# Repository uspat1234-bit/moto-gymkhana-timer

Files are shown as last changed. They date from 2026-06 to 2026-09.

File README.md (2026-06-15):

# MGTS (Moto Gymkhana Timing System) 🏍️⏱️


[]()
[]()

モトジムカーナの競技向けに設計された、高可用性・超低遅延のハイブリッド計時システム（Hardware & Software）です。

## 概要 (Overview)
屋外の過酷な通信環境やノイズ（雨滴、落ち葉、遮断状態の継続など）に耐えうるインフラグレードの設計思想を取り入れています。センサーからのトリガー信号を、ルーター不要の超低遅延無線プロトコル（ESP-NOW）と、物理LAN（W5500モジュールによるUDPブロードキャスト）の2経路で同時に送信する **Active-Active型の超冗長ネットワークアーキテクチャ** を採用しています。

## 主な特徴 (Features)
* **究極のネットワーク冗長化:** L2層（ESP-NOW）とL3層（有線LAN）の同時パケット送出により、パケットロスを物理的に回避。
* **高精度なエッジトリガー制御:** 20msのソフトウェアデバウンスと送信ロック機構により、センサー前での滞留による通信ストームを完全に防止。
* **拡張性の高いPCアプリ連携:** 計時処理とマトリクスLED表示を行うメインコア基板から、JSON形式のUDPパケットでPC（Flutter/Fletアプリ）へ結果をリアルタイム送信。
* **Hardware as Code:** 回路図や基板レイアウトはテキスト（JSONベース）でGit管理され、完全なトレーサビリティを確保。

## ハードウェア・インターフェース仕様 (Hardware Interfaces)

### メインLED基板 (Main Display Core)
筐体にマウントされた物理アーケードボタン（GPIO 22）を用いて、運用時のリカバリー操作やモード切替を行います。
* **短押し (50ms ～ 2秒未満): 強制DNF（リタイア）処理**
  * 転倒やコースアウト時など、現在計測中のランナーの記録を即座に「999.999 (DNF)」として確定・送信し、次の出走者の計測待機状態へ強制移行します。
* **長押し (2秒以上): シングルセンサーモード切替**
  * 画面に「SINGLE ON / OFF」と表示され、モードがトグルで切り替わります。
  * **SINGLE ON:** 8の字練習などで、1つのセンサーを「スタート」と「ゴール」の両方に兼用（ラップ計測）するモードです。

### センサーノード基板 (Sensor Node)
* **センサー入力 (GPIO 21):**
  * OMRON製光電センサー（E3Z-R66など）からのNPN信号を監視します。
  * 遮断された瞬間のエッジを検知し、チャタリングフィルター（20ms）を通過後、システム全体へトリガーパケットを送出します。

## システムアーキテクチャ (Architecture)

1. **Sensor Node (スタート / ゴール)**
   * XIAO ESP32-C6 + W5500モジュールで構成。
   * トリガー検知と同時に `START` または `STOP` コマンドを無線/有線でマルチキャスト。
2. **Main Display Core (LEDパネル基板)**
   * センサーからのコマンドを非同期で待ち受ける計時サーバー。
   * 64x8 マトリクスLEDによるリアルタイムな状態表示とタイム描画。
3. **Frontend App (PC側)**
   * Python/Fletで構築されたフロントエンドUI。
   * UDP経由での確定リザルト受信、および任意のエントリー番号予約や強制DNFコマンドの送信。

## ディレクトリ構成 (Directory Structure)

モノレポ（Monorepo）構成を採用し、ハードウェア構成とソフトウェアのバージョン整合性を担保しています。

```text
.
├── README.md                 # 本ドキュメント
├── hardware/                 # ハードウェア設計ファイル・BOM
│   ├── BOM.md                # 統合部品表（メイン表示部・センサーノード部）
│   ├── main_board/           # メインLED基板の回路図およびPCBレイアウト (EasyEDA)
│   └── sensor_node/          # センサー基板の回路図およびPCBレイアウト (EasyEDA)
├── esp32-c6_sketch/          # XIAO ESP32-C6用 ファームウェアソース (Arduino C++)
│   ├── main_board/
│   └── sensor_node/
└── app/                      # PC側表示・管理用アプリケーション (Python/Flet) ※今後実装予定

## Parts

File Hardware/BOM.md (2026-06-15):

# MGTS (Moto Gymkhana Timing System) 総合部品表 (BOM)

本ドキュメントは、計時システム（MGTS）を構成する「メイン表示部（LEDパネル）」および「センサーノード部（スタート・ゴール）」の調達部品一式を管理する構成管理データです。

---

## 1. メイン表示部 (LEDパネル側) × 1台分

| 大項目 | 品目 | 数量 | 金額 | 購入先リンク / 備考 |
| :--- | :--- | :---: | :---: | :--- |
| 内部基板 | 基板 | 1 | 160円 | [JLCPCB][1] |
| 内部基板 | ESP32-C6 | 1 | 1,650円 | [Amazon：マイコン本体][2] (3個パックを流用) |
| 内部基板 | ヒートシンク | 4 | 460円 | [Amazon：ヒートシンク][3] |
| 内部基板 | ダウンコンバータ | 2 | 260円 | [Amazon：ダウンコンバータ][4] |
| 内部基板 | W5500 | 1 | 833円 | [Amazon：W5500モジュール][5] |
| 内部基板 | 抵抗(10K) | 1 | 10円 | [Amazon：抵抗アソートパック][6] |
| 内部基板 | 抵抗(330) | 1 | 10円 | [Amazon：抵抗アソートパック][6] |
| 内部基板 | XHソケット(2pin) | 4 | 200円 | [Amazon：XHコネクタキット][7] |
| 内部基板 | XHソケット(3pin） | 1 | 50円 | [Amazon：XHコネクタキット][7] |
| 内部基板 | コンデンサ(1000uf) | 3 | 213円 | [Amazon：コンデンサ1000uf][8] |
| インターフェイス | LANポート | 1 | 350円 | [Amazon：パネルマウントLAN][11] |
| インターフェイス | wifiアンテナ | 1 | 450円 | [Amazon：アンテナ本体][12] |
| インターフェイス | wifiアンテナケーブル | 1 | 172円 | [Amazon：アンテナ用ケーブル][13] |
| インターフェイス | DCジャック | 1 | 44円 | [Amazon：パネルマウントDCジャック][14] |
| インターフェイス | 12vPDケーブル | 1 | 600円 | [Amazon：Type-C PDトリガーケーブル][15] |
| インターフェイス | 内部配線と接続ジャック | - | - | [Amazon：内部配線][16] / [Amazon：ジャック][17] |
| インターフェイス | USBポート | 1 | 700円 | [Amazon：パネルマウントUSB][25] |
| インターフェイス | アーケードボタン | 1 | 362円 | [Amazon：三和 OBSF-30][26] (物理リセット/モード切替) |
| ケース関連 | ケース | 1 | - | 既存資産流用または別途調達 |
| ケース関連 | スタンド台座 | 2 | 1,060円 | [Amazon：スタンド台座][20] |
| ケース関連 | ファン(共通) | 1 | 225円 | [Amazon：5Vファン][21] |
| ケース関連 | ファン(シロッコ) | 1 | 1,200円 | [Amazon：シロッコファン][27] (排熱用強力ブロワー) |
| ケース関連 | ファンフィルター | 1 | 146円 | [Amazon：ファンフィルター][22] |
| ケース関連 | HX分岐ファン用 | 1 | 100円 | [Amazon：ファン用分岐ケーブル][28] |
| ケース関連 | LEDパネル | 2 | 6,400円 | [Amazon：64x8 LEDマトリクス][29] |
| ケース関連 | LEDパネル保護板 | 1 | 1,500円 | [はざいや：アクリル板(グレースモーク)][30] (直射日光対策) |
| ケース関連 | ケース固定ステー | 2 | 1,140円 | [Amazon：固定ステー][31] |
| ケース関連 | パネル用両面テープ | 1 | 1,500円 | [Amazon：超強力両面テープ][32] |
| その他 | モバイルバッテリー | 1 | 8,000円 | [Amazon：アンカー大容量バッテリー][23] (87w/20000mAh) |
| その他 | LANケーブル | 1 | - | 既存資産流用 |
| その他 | スタンド | 2 | - | 既存資産流用 |
| その他 | ケース保護角 | 2 | 176円 | [Amazon：コーナーガード][33] |

---

## 2. センサーノード部 (スタート / ゴール共通) × 2台分合計

| 大項目 | 品目 | 数量 | 金額 | 購入先リンク / 備考 |
| :--- | :--- | :---: | :---: | :--- |
| 内部基板 | 基板 | 2 | 320円 | [JLCPCB][1] |
| 内部基板 | ESP32-C6 | 2 | 3,300円 | [Amazon：マイコン本体][2] (3個パック) |
| 内部基板 | ヒートシンク | 6 | 690円 | [Amazon：ヒートシンク][3] |
| 内部基板 | ダウンコンバータ | 2 | 260円 | [Amazon：ダウンコンバータ][4] |
| 内部基板 | W5500 | 2 | 1,666円 | [Amazon：W5500モジュール][5] |
| 内部基板 | 抵抗(10K) | 2 | 20円 | [Amazon：抵抗アソートパック][6] |
| 内部基板 | 抵抗(1K) | 2 | 20円 | [Amazon：抵抗アソートパック][6] |
| 内部基板 | XHソケット(2pin) | 4 | 200円 | [Amazon：XHコネクタキット][7] |
| 内部基板 | XHソケット(3pin） | 2 | 100円 | [Amazon：XHコネクタキット][7] |
| 内部基板 | コンデンサ(1000uf) | 4 | 284円 | [Amazon：コンデンサ1000uf][8] |
| 内部基板 | コンデンサ(0.1uf) | 2 | 200円 | [Amazon：コンデンサ0.1uf][9] |
| 内部基板 | フォトカプラ | 2 | 180円 | [Amazon：フォトカプラ][10] (センサー信号の絶縁用) |
| インターフェイス | LANポート | 2 | 700円 | [Amazon：パネルマウントLAN][11] |
| インターフェイス | wifiアンテナ | 2 | 900円 | [Amazon：アンテナ本体][12] |
| インターフェイス | wifiアンテナケーブル | 2 | 344円 | [Amazon：アンテナ用ケーブル][13] |
| インターフェイス | DCジャック | 2 | 88円 | [Amazon：パネルマウントDCジャック][14] |
| インターフェイス | 12vPDケーブル | 2 | 1,200円 | [Amazon：Type-C PDトリガーケーブル][15] |
| インターフェイス | 内部配線と接続ジャック | - | - | [Amazon：内部配線][16] / [Amazon：ジャック][17] |
| インターフェイス | センサー | 2 | - | OMRON [E3Z-R66 公式製品ページ][18] |
| ケース関連 | ケース | 2 | 2,600円 | [Amazon：防水/防塵ケース][19] |
| ケース関連 | スタンド台座 | 2 | 1,060円 | [Amazon：スタンド台座][20] |
| ケース関連 | ファン | 2 | 450円 | [Amazon：5Vファン][21] |
| ケース関連 | ファンフィルター | 2 | 292円 | [Amazon：ファンフィルター][22] |
| その他 | モバイルバッテリー | 2 | 16,000円 | [Amazon：アンカー大容量バッテリー][23] (87w/20000mAh) |
| その他 | LANケーブル | 2 | - | 既存資産流用 |
| その他 | スタンド(本体と反射板) | 4 | - | 既存資産流用 |
| その他 | 反射板 | 2 | - | [モノタロウ：アクリル反射板][24] |

---

### 🔗 共通リファレンスURL定義（一元管理）

[1]: https://jlcpcb.com/jp/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
[2]: https://www.amazon.co.jp/XIAO-ESP32C6-3%E5%80%8B%E3%83%91%E3%83%83%E3%82%AF-2-4GHz-5-0%E3%80%81Zigbee%E3%80%81Mater%E3%80%81Thread%E3%80%81%E3%82%AA%E3%83%B3%E3%83%9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
[3]: https://www.amazon.co.jp/dp/B0F8V4H91N
[4]: https://www.amazon.co.jp/dp/B0CGVMRQXB
[5]: https://www.amazon.co.jp/dp/B0FZ42HVNH
[6]: https://www.amazon.co.jp/%E7%82%AD%E7%B4%A0%E7%9A%AE%E8%86%9C%E6%8A%B5%E6%8A%97%E5%99%A8-30%E7%A8%AE%E5%90%8410%E6%9C%AC-10%CE%A9%E3%80%9C1M%CE%A9-%E9%9B%BB%E5%AD%90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
[7]: https://www.amazon.co.jp/XH%E3%82%AD%E3%83%83%E3%83%88-XH%E5%9E%8B%E7%AB%AF%E5%AD%90-%E3%82%B3%E3%83%B3%E3%82%BF%E3%82%AF%E3%83%88%E3%83%94%E3%83%B3-2-54mm%E3%83%94%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
[8]: https://www.amazon.co.jp/dp/B0FP5FLN5M
[9]: https://www.amazon.co.jp/%E6%9D%91%E7%94%B0%E8%A3%BD%E4%BD%9C%E6%89%80-MURATA-%E7%A9%8D%E5%B1%A4%E3%82%BB%E3%83%A9%E3%83%A3%E3%83%9F%E3%83%83%E3%82%AF%E3%82%B3%E3%83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
[10]: https://www.amazon.co.jp/dp/B09ZQRX29R
[11]: https://www.amazon.co.jp/gp/product/B0989ZYJH8
[12]: https://www.amazon.co.jp/dp/B09JBMLWTT
[13]: https://www.amazon.co.jp/dp/B0931SL6LG
[14]: https://www.amazon.co.jp/dp/B0FQBRHRLY
[15]: https://www.amazon.co.jp/dp/B0D3QG33J7
[16]: https://www.amazon.co.jp/dp/B0DJPQ6KT3
[17]: https://www.amazon.co.jp/dp/B011IJUKC4
[18]: https://www.fa.omron.co.jp/product/item/E3Z-R66/
[19]: https://www.amazon.co.jp/dp/B0F1ZT5SKT
[20]: https://www.amazon.co.jp/dp/B0F21DBYRP
[21]: https://www.amazon.co.jp/dp/B0G7GJZ6JC
[22]: https://www.amazon.co.jp/dp/B0G2R57LNK
[23]: https://www.amazon.co.jp/dp/B0CXNVT5J4
[24]: https://www.monotaro.com/g/04975913/
[25]: https://www.amazon.co.jp/dp/B0G12TWVNH
[26]: https://www.amazon.co.jp/%E4%B8%89%E5%92%8C%E9%9B%BB%E5%AD%90-Sanwa-OBSF-30-K-%E3%83%8F%E3%83%A1%E8%BE%BC%E3%81%BF%E5%BC%8F%E6%8A%BC%E3%81%97%E3%83%9C%E3%82%BF%E3%83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
[27]: https://www.amazon.co.jp/dp/B09G5RC5FF
[28]: https://www.amazon.co.jp/dp/B0GKTWP3LL
[29]: https://www.amazon.co.jp/dp/B088M21SPB
[30]: https://www.hazaiya.co.jp/
[31]: https://www.amazon.co.jp/dp/B003UCG5Y0
[32]: https://www.amazon.co.jp/dp/B01BXNSL8K
[33]: https://www.amazon.co.jp/dp/B0F27MNCGT

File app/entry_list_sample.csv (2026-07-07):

タグID | ゼッケン | 選手名 | クラス
A001 | 1 | 山田 太郎 | A
A002 | 2 | 佐藤 次郎 | A
A003 | 3 | 鈴木 健太 | A
A004 | 4 | 高橋 大輔 | A
B001 | 11 | 田中 宏 | B
B002 | 12 | 伊藤 達也 | B
B003 | 13 | 渡辺 剛 | B
B004 | 14 | 山本 修 | B
C001 | 21 | 中村 翔 | C
C002 | 22 | 小林 誠 | C
C003 | 23 | 加藤 涼 | C
C004 | 24 | 吉田 優 | C
D001 | 31 | 山田 花子 | D
D002 | 32 | 佐藤 結衣 | D
D003 | 33 | 鈴木 美咲 | D
D004 | 34 | 高橋 凛 | D

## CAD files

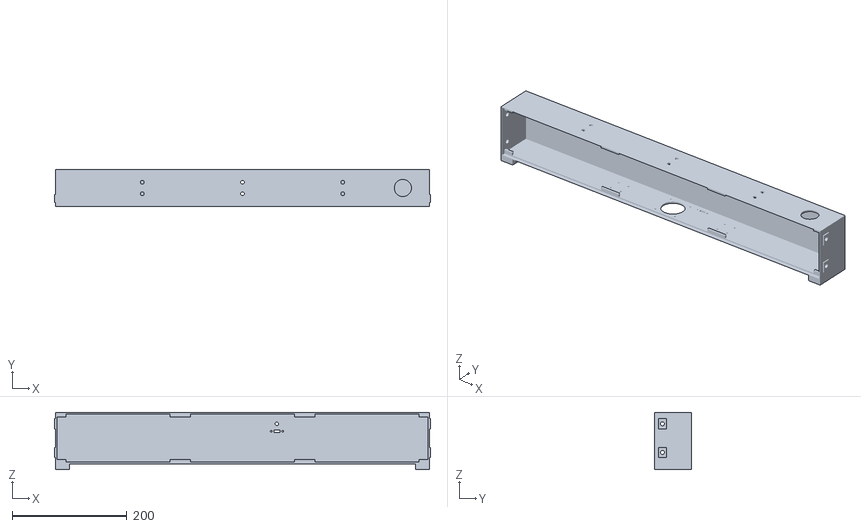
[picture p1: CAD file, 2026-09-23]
Hardware/case/full.stl
656.5 x 65.0 x 100.0

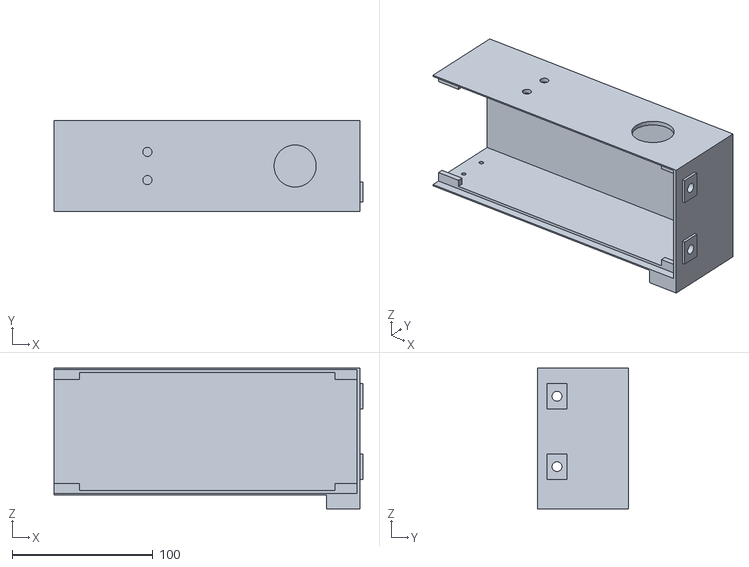
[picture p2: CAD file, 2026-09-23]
Hardware/case/right.stl
219.7 x 65.0 x 100.0

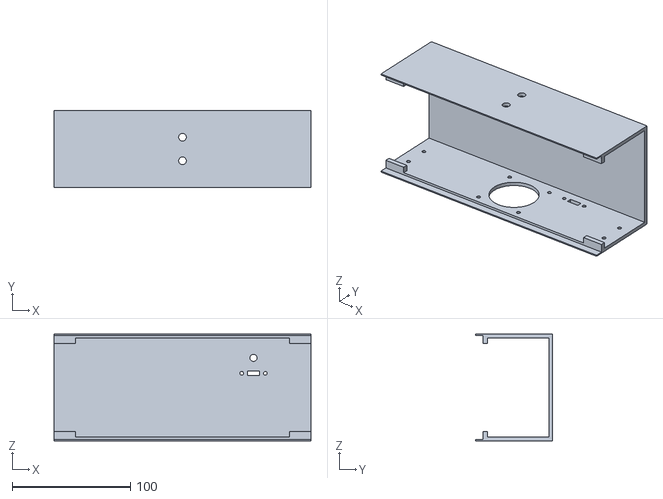
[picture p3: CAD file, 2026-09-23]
Hardware/case/center.stl
217.2 x 65.0 x 90.0

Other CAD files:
Hardware/case/left.stl

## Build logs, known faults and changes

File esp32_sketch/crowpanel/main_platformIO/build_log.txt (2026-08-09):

Processing advance-hmi (platform: https://github.com/Jason2866/platform-espressif32.git; board: ESP32-S3-WROOM-1-N16R8; framework: arduino)
--------------------------------------------------------------------------------
Verbose mode can be enabled via `-v, --verbose` option
CONFIGURATION: https://docs.platformio.org/page/boards/espressif32/ESP32-S3-WROOM-1-N16R8.html
PLATFORM: Espressif 32 (2026.6.50+sha.2979fbd) > ESP32-S3-16MB-Flash-8MB-PSRAM
HARDWARE: ESP32S3 240MHz, 8MB RAM, 16MB Flash
DEBUG: Current (esp-builtin) On-board (esp-builtin) External (cmsis-dap, esp-bridge, esp-prog, esp-prog-2, iot-bus-jtag, jlink, minimodule, olimex-arm-usb-ocd, olimex-arm-usb-ocd-h, olimex-arm-usb-tiny-h, olimex-jtag-tiny, tumpa)
PACKAGES: 
 - contrib-piohome @ 3.4.4 
 - framework-arduinoespressif32 @ 3.3.10+sha.67336dba 
 - tool-esptoolpy @ 5.3.0 
 - tool-xtensa-esp-elf-gdb @ 17.1.0+20260402 
 - toolchain-xtensa-esp-elf @ 15.2.0+20251204
LDF: Library Dependency Finder -> https://bit.ly/configure-pio-ldf
LDF Modes: Finder ~ chain, Compatibility ~ soft
Library Manager: Installing WiFiClientSecure
Warning! Could not find the package with 'WiFiClientSecure' requirements
Found 39 compatible libraries
Scanning dependencies...
Dependency Graph
|-- lvgl @ 8.3.11
|-- LovyanGFX @ 1.2.19
|-- Adafruit SSD1306 @ 2.5.13
|-- TAMC_GT911 @ 1.0.2
|-- TCA9554 @ 0.1.1
|-- Adafruit BusIO @ 1.17.0
|-- ArduinoJson @ 6.21.6
|-- RTClib @ 2.1.4
|-- FS @ 3.3.10
|-- LittleFS @ 3.3.10
|-- SD @ 3.3.10
|-- SPI @ 3.3.10
|-- Wire @ 3.3.10
Building in release mode
Linking .pio\build\advance-hmi\firmware.elf
C:\Users\admin\.platformio\penv\Scripts\platformio.exe : C:/Users/admin/.platformio/packages/toolchain-xtensa
-esp-elf/bin/../lib/gcc/xtensa-esp-elf/15.2.0/../../../../xtensa-esp-elf/bin/ld.exe: .pio/build/advance-hmi/s
rc/ui_events.cpp.o (symbol from plugin): in function `pt_count':
発生場所 行:1 文字:1
+ C:\Users\admin\.platformio\penv\Scripts\platformio.exe run > build_lo ...
+ ~~~~~~~~~~~~~~~~~~~~~~~~~~~~~~~~~~~~~~~~~~~~~~~~~~~~~~~~~~~~~~~~~~~~~
    + CategoryInfo          : NotSpecified: (C:/Users/admin/...ion `pt_count'::String) [], RemoteException
    + FullyQualifiedErrorId : NativeCommandError
 
(.text+0x0): multiple definition of `pt_count'; .pio/build/advance-hmi/src/main.cpp.o (symbol from plugin):(.
text+0x0): first defined here
C:/Users/admin/.platformio/packages/toolchain-xtensa-esp-elf/bin/../lib/gcc/xtensa-esp-elf/15.2.0/../../../..
/xtensa-esp-elf/bin/ld.exe: .pio/build/advance-hmi/src/ui_events.cpp.o (symbol from plugin): in function `pt_
count':
(.text+0x0): multiple definition of `is_mc'; .pio/build/advance-hmi/src/main.cpp.o (symbol from plugin):(.tex
t+0x0): first defined here
.pio/libdeps/advance-hmi/LovyanGFX/src/lgfx/v1/LGFXBase.hpp:1390:9: warning: type 'struct LovyanGFX' violates
 the C++ One Definition Rule [-Wodr]
 1390 |   class LovyanGFX : public
      |         ^
.pio/libdeps/advance-hmi/LovyanGFX/src/lgfx/v1/LGFXBase.hpp:1390:9: note: a type with the same name but diffe
rent base type is defined in another translation unit
 1390 |   class LovyanGFX : public
      |         ^
.pio/libdeps/advance-hmi/LovyanGFX/src/lgfx/v1/lgfx_filesystem_support.hpp:45:9: note: type name 'lgfx::v1::L
GFX_FILESYSTEM_Support<lgfx::v1::LGFXBase>' should match type name 'lgfx::v1::LGFXBase'
   45 |   class LGFX_FILESYSTEM_Support : public Base
      |         ^
.pio/libdeps/advance-hmi/LovyanGFX/src/lgfx/v1/LGFXBase.hpp:56:9: note: the incompatible type is defined here
   56 |   class LGFXBase
      |         ^
.pio/libdeps/advance-hmi/LovyanGFX/src/lgfx/v1/LGFXBase.hpp:1405:9: warning: type 'struct LGFX_Device' violat
es the C++ One Definition Rule [-Wodr]
 1405 |   class LGFX_Device : public LovyanGFX
      |         ^
.pio/libdeps/advance-hmi/LovyanGFX/src/lgfx/v1/LGFXBase.hpp:1405:9: note: a type with different bases is defi
ned in another translation unit
 1405 |   class LGFX_Device : public LovyanGFX
      |         ^
.pio/libdeps/advance-hmi/LovyanGFX/src/lgfx/v1/LGFXBase.hpp:1508:18: warning: type of 'init_impl' does not ma
tch original declaration [-Wlto-type-mismatch]
 1508 |     virtual bool init_impl(bool use_reset, bool use_clear);
      |                  ^
.pio/libdeps/advance-hmi/LovyanGFX/src/lgfx/v1/LGFXBase.cpp:3521:8: note: 'init_impl' was previously declared
 here
 3521 |   bool LGFX_Device::init_impl(bool use_reset, bool use_clear)
      |        ^
.pio/libdeps/advance-hmi/LovyanGFX/src/lgfx/v1/LGFXBase.cpp:3521:8: note: code may be misoptimized unless '-f
no-strict-aliasing' is used
.pio/libdeps/advance-hmi/LovyanGFX/src/lgfx/v1/LGFXBase.hpp:1408:5: warning: type of '__ct_base ' does not ma
tch original declaration [-Wlto-type-mismatch]
 1408 |     LGFX_Device(void);
      |     ^
.pio/libdeps/advance-hmi/LovyanGFX/src/lgfx/v1/LGFXBase.cpp:3498:3: note: '__ct_base ' was previously declare
d here
 3498 |   LGFX_Device::LGFX_Device(void)
      |   ^
.pio/libdeps/advance-hmi/LovyanGFX/src/lgfx/v1/LGFXBase.cpp:3498:3: note: code may be misoptimized unless '-f
no-strict-aliasing' is used
.pio/libdeps/advance-hmi/LovyanGFX/src/lgfx/v1/LGFXBase.hpp:1416:10: warning: type of 'setPanel' does not mat
ch original declaration [-Wlto-type-mismatch]
 1416 |     void setPanel(Panel_Device* panel);
      |          ^
.pio/libdeps/advance-hmi/LovyanGFX/src/lgfx/v1/LGFXBase.cpp:3513:8: note: 'setPanel' was previously declared 
here
 3513 |   void LGFX_Device::setPanel(Panel_Device* panel)
      |        ^
.pio/libdeps/advance-hmi/LovyanGFX/src/lgfx/v1/LGFXBase.cpp:3513:8: note: code may be misoptimized unless '-f
no-strict-aliasing' is used
lto-wrapper.exe: warning: using serial compilation of 8 LTRANS jobs
lto-wrapper.exe: note: see the '-flto' option documentation for more information
.pio/libdeps/advance-hmi/LovyanGFX/src/lgfx/v1/LGFXBase.hpp:1390:9: warning: type 'struct LovyanGFX' violates
 the C++ One Definition Rule [-Wodr]
 1390 |   class LovyanGFX : public
      |         ^
.pio/libdeps/advance-hmi/LovyanGFX/src/lgfx/v1/LGFXBase.hpp:1390:9: note: a type with the same name but diffe
rent base type is defined in another translation unit
.pio/libdeps/advance-hmi/LovyanGFX/src/lgfx/v1/lgfx_filesystem_support.hpp:45:9: note: type name 'lgfx::v1::L
GFX_FILESYSTEM_Support<lgfx::v1::LGFXBase>' should match type name 'lgfx::v1::LGFXBase'
   45 |   class LGFX_FILESYSTEM_Support : public Base
      |         ^
.pio/libdeps/advance-hmi/LovyanGFX/src/lgfx/v1/LGFXBase.hpp:56:9: note: the incompatible type is defined here
   56 |   class LGFXBase
      |         ^
.pio/libdeps/advance-hmi/LovyanGFX/src/lgfx/v1/LGFXBase.hpp:1390:9: warning: type 'struct LovyanGFX' violates
 the C++ One Definition Rule [-Wodr]
 1390 |   class LovyanGFX : public
      |         ^
.pio/libdeps/advance-hmi/LovyanGFX/src/lgfx/v1/LGFXBase.hpp:1390:9: note: a type with the same name but diffe
rent base type is defined in another translation unit
.pio/libdeps/advance-hmi/LovyanGFX/src/lgfx/v1/lgfx_filesystem_support.hpp:45:9: note: type name 'lgfx::v1::L
GFX_FILESYSTEM_Support<lgfx::v1::LGFXBase>' should match type name 'lgfx::v1::LGFXBase'
   45 |   class LGFX_FILESYSTEM_Support : public Base
      |         ^
.pio/libdeps/advance-hmi/LovyanGFX/src/lgfx/v1/LGFXBase.hpp:56:9: note: the incompatible type is defined here
   56 |   class LGFXBase
      |         ^
.pio/libdeps/advance-hmi/LovyanGFX/src/lgfx/v1/LGFXBase.hpp:1390:9: warning: type 'struct LovyanGFX' violates
 the C++ One Definition Rule [-Wodr]
 1390 |   class LovyanGFX : public
      |         ^
.pio/libdeps/advance-hmi/LovyanGFX/src/lgfx/v1/LGFXBase.hpp:1390:9: note: a type with the same name but diffe
rent base type is defined in another translation unit
.pio/libdeps/advance-hmi/LovyanGFX/src/lgfx/v1/lgfx_filesystem_support.hpp:45:9: note: type name 'lgfx::v1::L
GFX_FILESYSTEM_Support<lgfx::v1::LGFXBase>' should match type name 'lgfx::v1::LGFXBase'
   45 |   class LGFX_FILESYSTEM_Support : public Base
      |         ^
.pio/libdeps/advance-hmi/LovyanGFX/src/lgfx/v1/LGFXBase.hpp:56:9: note: the incompatible type is defined here
   56 |   class LGFXBase
      |         ^
collect2.exe: error: ld returned 1 exit status
*** [.pio\build\advance-hmi\firmware.elf] Error 1
========================= [FAILED] Took 18.55 seconds =========================

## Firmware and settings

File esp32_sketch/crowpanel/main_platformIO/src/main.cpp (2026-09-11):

#include "pins_config.h"
#include "LovyanGFX_Driver.h"

#include <Arduino.h>
#include <lvgl.h>
#include <Wire.h>
#include <SPI.h>
#include <SD.h>
#include <stdbool.h>
#include <ArduinoJson.h>
#include <RTClib.h>
#include <vector>
#include <map>

#include "ui.h"

// ==========================================
// ハードウェアピン設定
// ==========================================
#define SD_MOSI 6
#define SD_MISO 4
#define SD_SCK  5
#define SD_CS   7

// ==========================================
// ハードウェア・ディスプレイ用オブジェクト
// ==========================================
LGFX gfx;
RTC_PCF8563 rtc;
unsigned long lastTimeUpdate = 0;

// RTCから起動時に1回だけ取得した基準時刻 (GT911初期化後はRTCへの再アクセスを避けるため)
DateTime bootDateTime;
unsigned long bootMillis = 0;

DateTime getRtcNowCached() {
    unsigned long elapsedSec = (millis() - bootMillis) / 1000;
    return bootDateTime + TimeSpan(elapsedSec);
}

SPIClass SD_SPI = SPIClass(HSPI);

HardwareSerial C6Serial(1);

static lv_disp_draw_buf_t draw_buf;
static lv_color_t *buf;
static lv_color_t *buf1;

uint16_t touch_x, touch_y;

LV_FONT_DECLARE(font_jp_14);

unsigned long lastC6DataMillis = 0;
bool c6Connected = false;
unsigned long lastC6StatusCheck = 0;

// MC自動判定用の下限タイム(秒)。0以下の場合は自動判定を行わない
float mcThresholdSeconds = 0.0f;

lv_obj_t * current_editing_row = NULL;

extern int pt_count;
extern bool is_mc;

void on_master_row_clicked(lv_event_t * e) {
    current_editing_row = lv_event_get_target(e);
    lv_obj_clear_flag(ui_Panel4, LV_OBJ_FLAG_HIDDEN);

    lv_obj_t * no_label = ui_comp_get_child(current_editing_row, UI_COMP_MASTERROW_MASTERROW1NO);
    lv_obj_t * class_label = ui_comp_get_child(current_editing_row, UI_COMP_MASTERROW_MASTERROW1CLASS);
    lv_textarea_set_placeholder_text(ui_TextArea2, lv_label_get_text(no_label));
    lv_textarea_set_placeholder_text(ui_TextArea3, lv_label_get_text(class_label));

    lv_textarea_set_text(ui_TextArea2, "");
    lv_textarea_set_text(ui_TextArea3, "");

    pt_count = 0;
    is_mc = false;
    lv_label_set_text(ui_Label33, "+ 0 Sec");
    lv_keyboard_set_textarea(ui_Keyboard2, ui_TextArea2);
}

struct RiderInfo {
    String tagId;
    String bib;
    String lastName;
    String firstName;
    String riderClass;
};
std::vector<RiderInfo> riderDatabase;

struct ResultRecord {
    String tagId;
    String bib;
    String name;
    String riderClass;
    float  baseTime;
    int    penaltySeconds;
    bool   isMC;
    float  finalTime;
    String reactText;
    unsigned long recvMillis;
    lv_obj_t * rowObj;
};
std::vector<ResultRecord> masterLogs;

std::map<String, String> pendingNotes;
std::map<String, int> bestIndexByBib;
std::map<String, int> bibBestIndex;   // bib単位でのベスト記録（pb_日付.csv保存専用。ランキング集約とは独立）

std::vector<String> classList;
String masterTargetClass = "X";
String resultFilterClass = "ALL";

int unknownCounter = 0;

void rebuildResultTab();
void registerClass(String className);
void updateClassDropdown();
void savePersonalBestToSD();

void set_backlight(uint8_t brightness) {
    if (brightness > 245) brightness = 245;
    Wire.beginTransmission(0x30);
    Wire.write(brightness);
    Wire.endTransmission();
}
void buzzer_start() { Wire.beginTransmission(0x30); Wire.write(246); Wire.endTransmission(); }
void buzzer_stop()  { Wire.beginTransmission(0x30); Wire.write(247); Wire.endTransmission(); }
void speaker_on()   { Wire.beginTransmission(0x30); Wire.write(248); Wire.endTransmission(); }
void speaker_off()  { Wire.beginTransmission(0x30); Wire.write(249); Wire.endTransmission(); }

void my_disp_flush(lv_disp_drv_t *disp, const lv_area_t *area, lv_color_t *color_p) {
    if (gfx.getStartCount() > 0) gfx.endWrite();
    gfx.pushImageDMA(area->x1, area->y1, area->x2 - area->x1 + 1, area->y2 - area->y1 + 1, (lgfx::rgb565_t *)&color_p->full);
    lv_disp_flush_ready(disp);
}
void my_touchpad_read(lv_indev_drv_t * indev_driver, lv_indev_data_t * data) {
    data->state = LV_INDEV_STATE_REL;
    bool touched = gfx.getTouch(&touch_x, &touch_y);
    if (touched) {
        data->state = LV_INDEV_STATE_PR;
        data->point.x = touch_x;
        data->point.y = touch_y;
    }
}

String formatTime(float t) {
    if (t < 0) return "-";
    int minutes = (int)t / 60;
    float seconds = t - (minutes * 60.0f);
    char buf[16];
    snprintf(buf, sizeof(buf), "%d:%06.3f", minutes, seconds);
    return String(buf);
}

String buildPenMemoText(const ResultRecord &r) {
    if (r.isMC) return "MC";
    if (r.penaltySeconds > 0) return "+" + String(r.penaltySeconds) + "s";
    return "";
}

String buildFullName(const String &lastName, const String &firstName) {
    String trimmedFirst = firstName;
    trimmedFirst.trim();
    if (trimmedFirst.length() == 0) {
        return lastName;
    }
    return lastName + "　" + trimmedFirst;
}

void loadEntryList() {
    riderDatabase.clear();
    File file = SD.open("/entry_list.csv", FILE_READ);
    if (!file) {
        Serial.println("entry_list.csv が見つかりません");
        return;
    }

    bool isHeader = true;
    while (file.available()) {
        String line = file.readStringUntil('\n');
        line.trim();
        if (line.length() == 0) continue;
        if (isHeader) { isHeader = false; continue; }

        int idx1 = line.indexOf(',');
        int idx2 = line.indexOf(',', idx1 + 1);
        int idx3 = line.indexOf(',', idx2 + 1);
        int idx4 = line.indexOf(',', idx3 + 1);
        if (idx1 < 0 || idx2 < 0 || idx3 < 0 || idx4 < 0) continue;

        RiderInfo info;
        info.tagId      = line.substring(0, idx1);
        info.bib        = line.substring(idx1 + 1, idx2);
        info.lastName   = line.substring(idx2 + 1, idx3);
        info.firstName  = line.substring(idx3 + 1, idx4);
        info.riderClass = line.substring(idx4 + 1);
        info.tagId.trim(); info.bib.trim(); info.lastName.trim(); info.firstName.trim(); info.riderClass.trim();

        riderDatabase.push_back(info);
        registerClass(info.riderClass);
    }
    file.close();
    Serial.printf("選手名簿読込完了: %d 名\n", riderDatabase.size());
    updateClassDropdown();
}

RiderInfo* findRiderByTagId(const String &tagId) {
    for (auto &r : riderDatabase) if (r.tagId == tagId) return &r;
    return nullptr;
}
RiderInfo* findRiderByBib(const String &bib) {
    for (auto &r : riderDatabase) if (r.bib == bib) return &r;
    return nullptr;
}

void registerClass(String className) {
    className.trim();
    if (className.length() == 0) return;
    for (auto &c : classList) {
        if (c == className) return;
    }
    classList.push_back(className);
    updateClassDropdown();
}

void updateClassDropdown() {
    String options = "ALL";
    for (auto &c : classList) {
        options += "\n" + c;
    }
    lv_dropdown_set_options(ui_Dropdown1, options.c_str());
}

float getPreviousBestTime(const String &tagId, const String &bib, int excludeIndex) {
    float best = -1.0f;
    for (int i = 0; i < (int)masterLogs.size(); i++) {
        if (i == excludeIndex) continue;
        ResultRecord &r = masterLogs[i];
        if (r.isMC) continue;
        bool sameRider = false;
        if (tagId != "X999") {
            sameRider = (r.tagId == tagId);
        } else {
            sameRider = (r.tagId == "X999"); // X999同士は常に同一人物とみなす
        }
        if (sameRider) {
            if (best < 0 || r.finalTime < best) best = r.finalTime;
        }
    }
    return best;
}

float getOverallTopTime() {
    float top = -1.0f;
    for (auto &r : masterLogs) {
        if (r.isMC) continue;
        if (top < 0 || r.finalTime < top) top = r.finalTime;
    }
    return top;
}

float getClassTopTime(const String &riderClass) {
    float top = -1.0f;
    for (auto &r : masterLogs) {
        if (r.isMC) continue;
        if (r.riderClass != riderClass) continue;
        if (top < 0 || r.finalTime < top) top = r.finalTime;
    }
    return top;
}

void addMasterRowUI(int index) {
    ResultRecord &r = masterLogs[index];

    lv_obj_t * row = ui_MasterRow_create(ui_ListContainer);
    lv_obj_set_user_data(row, (void*)(intptr_t)index);
    lv_obj_add_event_cb(row, on_master_row_clicked, LV_EVENT_CLICKED, NULL);
    lv_obj_move_to_index(row, 0);

    lv_obj_t * rank_label  = ui_comp_get_child(row, UI_COMP_MASTERROW_MASTERROW1RANK);
    lv_obj_t * class_label = ui_comp_get_child(row, UI_COMP_MASTERROW_MASTERROW1CLASS);
    lv_obj_t * no_label    = ui_comp_get_child(row, UI_COMP_MASTERROW_MASTERROW1NO);
    lv_obj_t * name_label  = ui_comp_get_child(row, UI_COMP_MASTERROW_MASTERROW1NAME);
    lv_obj_t * time_label  = ui_comp_get_child(row, UI_COMP_MASTERROW_MASTERROW1TIME);
    lv_obj_t * react_label = ui_comp_get_child(row, UI_COMP_MASTERROW_MASTERROW1REACT);
    lv_obj_t * memo_label  = ui_comp_get_child(row, UI_COMP_MASTERROW_MASTERROW1PENMEMO);

    lv_obj_set_style_text_font(name_label, &font_jp_14, 0);
    lv_label_set_long_mode(name_label, LV_LABEL_LONG_CLIP);
    lv_obj_set_height(name_label, LV_SIZE_CONTENT);

    lv_label_set_text_fmt(rank_label, "%d", (int)masterLogs.size());
    lv_label_set_text(class_label, r.riderClass.c_str());
    lv_label_set_text(no_label, r.bib.c_str());
    lv_label_set_text(name_label, r.name.c_str());
    lv_label_set_text(time_label, r.isMC ? "MC" : formatTime(r.finalTime).c_str());
    lv_label_set_text(react_label, r.reactText.c_str());
    lv_label_set_text(memo_label, buildPenMemoText(r).c_str());

    r.rowObj = row;
}

void refreshMasterRowUI(int index) {
    ResultRecord &r = masterLogs[index];
    if (r.rowObj == nullptr) return;

    lv_obj_t * class_label = ui_comp_get_child(r.rowObj, UI_COMP_MASTERROW_MASTERROW1CLASS);
    lv_obj_t * no_label    = ui_comp_get_child(r.rowObj, UI_COMP_MASTERROW_MASTERROW1NO);
    lv_obj_t * name_label  = ui_comp_get_child(r.rowObj, UI_COMP_MASTERROW_MASTERROW1NAME);
    lv_obj_t * time_label  = ui_comp_get_child(r.rowObj, UI_COMP_MASTERROW_MASTERROW1TIME);
    lv_obj_t * memo_label  = ui_comp_get_child(r.rowObj, UI_COMP_MASTERROW_MASTERROW1PENMEMO);

    lv_obj_set_style_text_font(name_label, &font_jp_14, 0);
    lv_label_set_text(class_label, r.riderClass.c_str());
    lv_label_set_text(no_label, r.bib.c_str());
    lv_label_set_text(name_label, r.name.c_str());
    lv_label_set_text(time_label, r.isMC ? "MC" : formatTime(r.finalTime).c_str());
    lv_label_set_text(memo_label, buildPenMemoText(r).c_str());
}

void rebuildResultTab() {
    bestIndexByBib.clear();

    for (int i = 0; i < (int)masterLogs.size(); i++) {
        ResultRecord &r = masterLogs[i];
        if (r.isMC) continue;

        // bib単位で集計する（以前はtagId=="X999"の場合だけ全員まとめていたが、
        // 電源再投入後に復元された記録はtagIdが空文字になるため挙動が不整合になっていた。
        // bibは常にユニーク(X1, X2, X3...)なので、bib基準に統一する）
        String bestKey = r.bib;

        auto it = bestIndexByBib.find(bestKey);
        if (it == bestIndexByBib.end()) {
            bestIndexByBib[bestKey] = i;
        } else {
            if (r.finalTime < masterLogs[it->second].finalTime) {
                it->second = i;
            }
        }
    }

    float overallBestTime = -1.0f;
    for (auto &kv : bestIndexByBib) {
        ResultRecord &r = masterLogs[kv.second];
        if (overallBestTime < 0 || r.finalTime < overallBestTime) {
            overallBestTime = r.finalTime;
        }
    }

    std::vector<int> candidates;
    for (auto &kv : bestIndexByBib) {
        ResultRecord &r = masterLogs[kv.second];
        if (resultFilterClass == "ALL" || r.riderClass == resultFilterClass) {
            candidates.push_back(kv.second);
        }
    }

    std::sort(candidates.begin(), candidates.end(), [](int a, int b) {
        ResultRecord &ra = masterLogs[a];
        ResultRecord &rb = masterLogs[b];
        if (ra.finalTime != rb.finalTime) return ra.finalTime < rb.finalTime;
        return ra.bib.toInt() < rb.bib.toInt();
    });

    if (candidates.size() > 5) candidates.resize(5);

    float topTime = overallBestTime;

    lv_obj_clean(ui_ListContainer2);

    for (int rank = 0; rank < (int)candidates.size(); rank++) {
        ResultRecord &r = masterLogs[candidates[rank]];

        lv_obj_t * row = ui_ResultRow_create(ui_ListContainer2);

        lv_obj_t * rank_label  = ui_comp_get_child(row, UI_COMP_RESULTROW_RESULTROW1RANK);
        lv_obj_t * class_label = ui_comp_get_child(row, UI_COMP_RESULTROW_RESULTROW1CLASS);
        lv_obj_t * no_label    = ui_comp_get_child(row, UI_COMP_RESULTROW_RESULTROW1NO);
        lv_obj_t * name_label  = ui_comp_get_child(row, UI_COMP_RESULTROW_RESULTROW1NAME);
        lv_obj_t * time_label  = ui_comp_get_child(row, UI_COMP_RESULTROW_RESULTROW1TIME);
        lv_obj_t * top_label   = ui_comp_get_child(row, UI_COMP_RESULTROW_RESULTROW1TOP);
        lv_obj_t * react_label = ui_comp_get_child(row, UI_COMP_RESULTROW_RESULTROW1REACT);
        lv_obj_t * memo_label  = ui_comp_get_child(row, UI_COMP_RESULTROW_RESULTROW1PENMEMO);

        lv_obj_set_style_text_font(name_label, &font_jp_14, 0);
        lv_label_set_text_fmt(rank_label, "%d", rank + 1);
        lv_label_set_text(class_label, r.riderClass.c_str());
        lv_label_set_text(no_label, r.bib.c_str());
        lv_label_set_text(name_label, r.name.c_str());
        lv_label_set_text(time_label, formatTime(r.finalTime).c_str());
        lv_label_set_text(react_label, r.reactText.c_str());
        lv_label_set_text(memo_label, buildPenMemoText(r).c_str());

        if (topTime <= 0) {
            lv_label_set_text(top_label, "100.000%");
        } else {
            float ratio = (r.finalTime / topTime) * 100.0f;
            int ratioX1000 = (int)(ratio * 1000.0f);   // 3桁精度で切り捨て
            char buf[16];
            snprintf(buf, sizeof(buf), "%d.%03d%%", ratioX1000 / 1000, ratioX1000 % 1000);
            lv_label_set_text(top_label, buf);
        }
    }
}

// ==========================================
// 個人ベストの永続化 (RTC安全読み取り版)
// ==========================================
String getPersonalBestFilename() {
    DateTime now = getRtcNowCached();
    char filename[32];
    sprintf(filename, "/pb_%04d%02d%02d.csv", now.year(), now.month(), now.day());
    return String(filename);
}

void savePersonalBestToSD() {
    String filename = getPersonalBestFilename();
    File f = SD.open(filename, FILE_WRITE);
    if (!f) {
        Serial.println(filename + " 書き込み失敗");
        return;
    }
    f.println("bib,name,class,time");
    for (auto &kv : bibBestIndex) {   // ★ bib単位の管理に変更（身元不明選手が1枠に集約されないように）
        ResultRecord &best = masterLogs[kv.second];
        f.printf("%s,%s,%s,%.3f\n",
            best.bib.c_str(), best.name.c_str(), best.riderClass.c_str(), best.finalTime);
    }
    f.close();
}

void loadPersonalBestFromSD() {
    String filename = getPersonalBestFilename();
    File f = SD.open(filename, FILE_READ);
    if (!f) {
        Serial.println(filename + " が見つかりません(本日はじめてのセッション)");
        return;
    }

    bool isHeader = true;
    while (f.available()) {
        String line = f.readStringUntil('\n');
        line.trim();
        if (line.length() == 0) continue;
        if (isHeader) { isHeader = false; continue; }

        int idx1 = line.indexOf(',');
        int idx2 = line.indexOf(',', idx1 + 1);
        int idx3 = line.indexOf(',', idx2 + 1);
        if (idx1 < 0 || idx2 < 0 || idx3 < 0) continue;

        ResultRecord rec;
        rec.bib = line.substring(0, idx1);
        rec.name = line.substring(idx1 + 1, idx2);
        rec.riderClass = line.substring(idx2 + 1, idx3);
        rec.finalTime = line.substring(idx3 + 1).toFloat();
        rec.baseTime = rec.finalTime;
        rec.penaltySeconds = 0;
        rec.isMC = false;
        rec.tagId = "";
        rec.rowObj = nullptr;

        masterLogs.push_back(rec);
        int idx = masterLogs.size() - 1;
        bestIndexByBib[rec.bib] = idx;
        bibBestIndex[rec.bib] = idx;   // ★ bib単位の管理にも復元する

        // bibが"X"+数字(例:"X12")の形式なら、unknownCounterを復元して番号の衝突を防ぐ
        if (rec.bib.startsWith("X")) {
            int num = rec.bib.substring(1).toInt();
            if (num > unknownCounter) unknownCounter = num;
        }

        registerClass(rec.riderClass);
    }
    f.close();
    Serial.printf("個人ベスト復元完了(%s): %d 名\n", filename.c_str(), bestIndexByBib.size());
}

// ==========================================
// MC threshold (下限タイムによる自動MC判定)
// ==========================================
void setMcThreshold(int minutes, int seconds, int ms100, int ms10, int ms1) {
    int milliseconds = ms100 * 100 + ms10 * 10 + ms1;
    mcThresholdSeconds = minutes * 60.0f + seconds + milliseconds / 1000.0f;
    Serial.printf("[MC閾値] 設定: %d分%02d秒.%03d (%.3f秒)\n",
        minutes, seconds, milliseconds, mcThresholdSeconds);
}

void processResult(String tagId, float rawTime) {
    RiderInfo* rider = findRiderByTagId(tagId);
    String bib, name, riderClass;

    if (tagId == "X999") {
        unknownCounter++;
        bib = "X" + String(unknownCounter);   // 例: "X1", "X15" など、短く表記
        name = "";
        riderClass = masterTargetClass;
    } else if (rider == nullptr) {
        bib = tagId;
        name = "";
        riderClass = masterTargetClass;
    } else {
        bib = rider->bib;
        name = buildFullName(rider->lastName, rider->firstName);
        riderClass = rider->riderClass;
    }

    registerClass(riderClass);

    ResultRecord rec;
    rec.tagId = tagId;
    rec.bib = bib;
    rec.name = name;
    rec.riderClass = riderClass;
    rec.baseTime = rawTime;
    rec.penaltySeconds = 0;

    // 下限タイムを下回っていたら、自動的にMC判定
    if (mcThresholdSeconds > 0 && rawTime < mcThresholdSeconds) {
        rec.isMC = true;
        Serial.printf("[自動MC] タイム %.3f秒 < 閾値 %.3f秒 のため、MC判定\n", rawTime, mcThresholdSeconds);
    } else {
        rec.isMC = false;
    }

    rec.finalTime = rec.isMC ? INFINITY : rawTime;
    rec.recvMillis = millis();
    rec.rowObj = nullptr;

    auto noteIt = pendingNotes.find(tagId);
    if (noteIt != pendingNotes.end()) {
        rec.reactText = noteIt->second;
        pendingNotes.erase(noteIt);
    }

    masterLogs.push_back(rec);
    int newIndex = masterLogs.size() - 1;

    // bib単位でのベスト記録を更新（保存用。ランキング集約(bestIndexByBib)とは独立して管理する）
    {
        auto bIt = bibBestIndex.find(bib);
        if (bIt == bibBestIndex.end() || masterLogs[newIndex].finalTime < masterLogs[bIt->second].finalTime) {
            bibBestIndex[bib] = newIndex;
        }
    }

    addMasterRowUI(newIndex);

    long total_ms = (long)round(rawTime * 1000.0);
    Serial0.printf("T:%ld\n", total_ms);

    // MC判定された場合、ファステスト系の読み上げは行わない(除外ロジックにより自動的に対象外)
    if (!rec.isMC) {
        float prevBest = getPreviousBestTime(tagId, bib, newIndex);
        bool isPersonalBest = (prevBest < 0 || rawTime < prevBest);

        float overallTop = getOverallTopTime();
        bool isOverallFastest = (fabs(rawTime - overallTop) < 0.0005f);

        if (isOverallFastest) {
            Serial0.println("W:overall_fastest");
        } else {
            float classTop = getClassTopTime(riderClass);
            bool isClassFastest = (fabs(rawTime - classTop) < 0.0005f);

            if (isClassFastest) {
                Serial0.println("W:class_fastest");
            }
            if (isPersonalBest) {
                Serial0.println("W:personal_best");
            }

            if (overallTop > 0) {
                float ratio = (rawTime / overallTop) * 100.0f;
                int ratioX10 = (int)(ratio * 10.0f); // 直接1桁精度で切り捨て
                Serial0.printf("P:%d\n", ratioX10);
            }
        }
    }

    rebuildResultTab();
    savePersonalBestToSD();
}

void processJsonMessage(String jsonStr) {
    StaticJsonDocument<256> doc;
    if (deserializeJson(doc, jsonStr)) return;

    String type = doc["type"].as<String>();
    String id = doc["id"] | "X999";

    if (type == "RESULT") {
        float t = doc["time"].as<float>();
        processResult(id, t);

    } else if (type == "REACTION") {
        float diff = doc["diff"] | 0.0f;
        pendingNotes[id] = "React:" + String(diff, 3) + "s";

    } else if (type == "FLYING") {
        float diff = doc["diff"] | 0.0f;
        pendingNotes[id] = "FLYING(" + String(diff, 3) + "s)";

    } else if (type == "SEQ_START") {
        Serial.println("[SEQ] シグナル開始");

    } else if (type == "FORCE_DNF") {
        Serial.println("[SEQ] コースリセット");
    }
}

void importCsvData() {
    Serial.println("UIから importCsvData が呼ばれました！");
    loadEntryList();
}

void sendManualTrigger(String type) {
    C6Serial.println(type);
    Serial.println("[MANUAL] " + type + " を送信しました");
}

void queueResultVoice(float total_seconds) {
    long ms = (long)round(total_seconds * 1000.0);
    Serial0.printf("T:%ld\n", ms);
}
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
void loop() {
    lv_timer_handler();
    delay(5);

    if (millis() - lastTimeUpdate > 1000) {
        updateTimeDisplay();
        lastTimeUpdate = millis();
    }

    if (millis() - lastC6StatusCheck > 10000) {
        updateC6ConnectionStatus();
        lastC6StatusCheck = millis();
    }

    if (C6Serial.available() > 0) {
        String input = C6Serial.readStringUntil('\n');
        input.trim();

        lastC6DataMillis = millis();

        Serial.println(input);

        if (input.startsWith("[ESP_DATA]")) {
            input.replace("[ESP_DATA]", "");
            input.trim();
            processJsonMessage(input);
        }
    }

    if (Serial.available() > 0) {
        String input = Serial.readStringUntil('\n');
        input.trim();
        if (input.startsWith("[ESP_DATA]")) {
            input.replace("[ESP_DATA]", "");
            input.trim();
            processJsonMessage(input);
        } else if (input.startsWith("{")) {
            processJsonMessage(input);
        }
    }
}

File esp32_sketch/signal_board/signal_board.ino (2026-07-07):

/*
 * ====================================================================
 * MGTS (Moto Gymkhana Timing System) - Signal Board Core Unit
 * * [Architecture Highlights]
 * 1. 自律型カウントダウンシーケンス (Autonomous Countdown Sequence)
 * 2. キャストガード・フライング判定 (Cast-Guard Flying Detection)
 * 3. 共通エッジ・ステート管理: メイン基板同様、基本を X999 とし
 * ENTRY受信でIDを更新。ペナルティ検知時はIDを付与して送信。
 * 4. 多重起動ロック (Sequence Execution Lock):
 * 既にシグナルが進行している状態(isSequenceActive)で
 * 重複してSEQ_STARTを受信した場合、連打とみなして安全に破棄する。
 * ====================================================================
 */

#include <SPI.h>
#include <Ethernet.h>
#include <WiFi.h>
#include <esp_now.h>
#include <esp_wifi.h>
#include <Adafruit_GFX.h>
#include <Adafruit_NeoMatrix.h>
#include <driver/i2s.h>
#include <math.h>
#include <ArduinoJson.h>

/* ====================================================================
 * L3 ネットワーク構成 (有線LAN / W5500)
 * ==================================================================== */
IPAddress ip_eth(192, 168, 1, 30);      
IPAddress dns(192, 168, 1, 1);
IPAddress gateway(192, 168, 1, 1);
IPAddress subnet(255, 255, 255, 0);
byte mac[] = { 0xDE, 0xAD, 0xBE, 0xEF, 0xFE, 0x30 }; 
const int UDP_PORT   = 5005;            

/* ====================================================================
 * ハードウェア・ピン定義
 * ==================================================================== */
#define LED_PIN       21  
#define BTN_RESET     22  

#define ETH_CS_PIN    1   
#define ETH_RST_PIN   2   
#define SPI_SCK       19  
#define SPI_MISO      20  
#define SPI_MOSI      18  

#define PIN_BCK       23  
#define PIN_LCK       16  
#define PIN_DIN       17  
#define I2S_NUM       I2S_NUM_0

Adafruit_NeoMatrix matrix = Adafruit_NeoMatrix(64, 8, LED_PIN,
  NEO_MATRIX_TOP + NEO_MATRIX_LEFT + NEO_MATRIX_COLUMNS + NEO_MATRIX_ZIGZAG,
  NEO_GRB + NEO_KHZ800);

EthernetUDP ethUdp;
char packetBuffer[512]; 

/* ====================================================================
 * シグナル制御構造・ステート管理
 * ==================================================================== */
uint8_t hubAddress[] = {0x58, 0xE6, 0xC5, 0x12, 0x97, 0xCC};

unsigned long seqStartTime = 0;
unsigned long expectedGreenTime = 0;
unsigned long flyingStartTime = 0;

bool isSequenceActive = false;
bool hasStartedPhysical = false;

enum SignalState { STATE_READY, STATE_DELAY, STATE_RED1, STATE_RED2, STATE_YELLOW, STATE_GREEN, STATE_FLYING };
SignalState currentSignalState = STATE_READY;

String nextRiderID = "X999";
String currentRiderId = "X999";

int16_t sine_table[256];

/* ====================================================================
 * ユーティリティ・コア関数
 * ==================================================================== */
void showStatus(String txt, uint16_t color) {
  matrix.setTextColor(color);
  int x = (64 - (txt.length() * 6)) / 2; 
  matrix.setCursor(x >= 0 ? x : 0, 1); matrix.print(txt);
}

void notifyControlHub(String eventType, String id, float diffSec) {
  String json = "{\"type\":\"" + eventType + "\",\"id\":\"" + id + "\",\"diff\":" + String(diffSec, 3) + "}";
  esp_now_send(hubAddress, (uint8_t *)json.c_str(), json.length());
  Serial.println("[NOTIFY] " + json);
}

void playTone(float frequency, unsigned long duration_ms) {
  size_t bw; unsigned long num_samples = (44100 * duration_ms) / 1000; int16_t buffer[1024]; uint32_t phase = 0; uint32_t phase_step = (frequency * 4294967296.0) / 44100.0; 
  unsigned long samples_sent = 0;
  while (samples_sent < num_samples) {
    int to_send = min((unsigned long)512, num_samples - samples_sent);
    for (int i = 0; i < to_send; i++) {
      int env = 256; if (samples_sent + i < 1000) env = ((samples_sent + i) * 256) / 1000; else if (num_samples - (samples_sent + i) < 1000) env = ((num_samples - (samples_sent + i)) * 256) / 1000;
      buffer[i*2] = (sine_table[phase >> 24] * env) >> 8; buffer[i*2+1] = buffer[i*2]; phase += phase_step; 
    }
    i2s_write(I2S_NUM, buffer, to_send * 4, &bw, portMAX_DELAY); samples_sent += to_send;
  }
  i2s_zero_dma_buffer(I2S_NUM);
}

void playPenaltySound() {
  for(int i = 0; i < 6; i++) {
    playTone(2000, 60); 
    playTone(1400, 60); 
  }
  playTone(800, 400);
}

/* ====================================================================
 * 上位プロトコル・コマンドハンドラ
 * ==================================================================== */
void processCommand(String rawMsg) {
  String msg = rawMsg; msg.trim(); 
  
  if (msg.startsWith("{")) {
    JsonDocument doc;
    if (!deserializeJson(doc, msg)) {
      if (doc["type"] == "ENTRY") nextRiderID = doc["id"].as<String>();
    }
    return;
  }
  
  if (msg == "SEQ_START") {
    // ★追加: 多重起動ロック (連打ガード)
    // 既にシグナル進行中の場合は、追加の開始要求を完全に無視する
    if (isSequenceActive) {
      Serial.println("[SEQ] Ignore: Sequence already running.");
      return;
    }

    currentRiderId = nextRiderID;
    nextRiderID = "X999";
    
    seqStartTime = millis();
    expectedGreenTime = seqStartTime + 5000; 
    isSequenceActive = true;
    hasStartedPhysical = false;
    currentSignalState = STATE_DELAY;
    Serial.println("[SEQ] Start sequence initiated for ID: " + currentRiderId);
  }
  else if (msg == "START") {
    if (!isSequenceActive || hasStartedPhysical) return;
    
    hasStartedPhysical = true; 
    long diffMs = (long)millis() - (long)expectedGreenTime;
    float diffSec = (float)diffMs / 1000.0; 
    
    if (diffMs < 0) { 
      currentSignalState = STATE_FLYING; 
      flyingStartTime = millis();
      notifyControlHub("FLYING", currentRiderId, diffSec); 
      playPenaltySound(); 
    } else {
      notifyControlHub("REACTION", currentRiderId, diffSec); 
    }
  } 
  else if (msg == "FORCE_DNF") { 
    isSequenceActive = false;
    currentSignalState = STATE_READY; 
  }
}

/* ====================================================================
 * ESP-NOW 受信コールバック
 * ==================================================================== */
void OnDataRecv(const esp_now_recv_info_t *recv_info, const uint8_t *incomingData, int len) {
  char msg[len + 1]; memcpy(msg, incomingData, len); msg[len] = '\0'; processCommand(String(msg));
}
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

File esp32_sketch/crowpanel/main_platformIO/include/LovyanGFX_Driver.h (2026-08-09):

#define LGFX_USE_V1
#include <LovyanGFX.hpp>
#include <lgfx/v1/platforms/esp32s3/Panel_RGB.hpp>
#include <lgfx/v1/platforms/esp32s3/Bus_RGB.hpp>
#include <driver/i2c.h>

class LGFX : public lgfx::LGFX_Device {
public:

  lgfx::Bus_RGB _bus_instance;
  lgfx::Panel_RGB _panel_instance;
  lgfx::Touch_GT911 _touch_instance;

  LGFX(void) {
    {
      auto cfg = _panel_instance.config();

      cfg.memory_width = 800;
      cfg.memory_height = 480;
      cfg.panel_width = 800;
      cfg.panel_height = 480;

      cfg.offset_x = 0;
      cfg.offset_y = 0;

      _panel_instance.config(cfg);
    }

    {
      auto cfg = _panel_instance.config_detail();

      cfg.use_psram = 1;

      _panel_instance.config_detail(cfg);
    }

    {
      auto cfg = _bus_instance.config();
      cfg.panel = &_panel_instance;
      cfg.pin_d0 = GPIO_NUM_21;    // B0
      cfg.pin_d1 = GPIO_NUM_47;    // B1
      cfg.pin_d2 = GPIO_NUM_48;   // B2
      cfg.pin_d3 = GPIO_NUM_45;    // B3
      cfg.pin_d4 = GPIO_NUM_38;    // B4
      cfg.pin_d5 = GPIO_NUM_9;    // G0
      cfg.pin_d6 = GPIO_NUM_10;    // G1
      cfg.pin_d7 = GPIO_NUM_11;    // G2
      cfg.pin_d8 = GPIO_NUM_12;   // G3
      cfg.pin_d9 = GPIO_NUM_13;   // G4
      cfg.pin_d10 = GPIO_NUM_14;   // G5
      cfg.pin_d11 = GPIO_NUM_7;  // R0
      cfg.pin_d12 = GPIO_NUM_17;  // R1
      cfg.pin_d13 = GPIO_NUM_18;  // R2
      cfg.pin_d14 = GPIO_NUM_3;  // R3
      cfg.pin_d15 = GPIO_NUM_46;  // R4

      cfg.pin_henable = GPIO_NUM_42;
      cfg.pin_vsync = GPIO_NUM_41;
      cfg.pin_hsync = GPIO_NUM_40;
      cfg.pin_pclk = GPIO_NUM_39;
      
      cfg.freq_write = 18000000;

      cfg.hsync_polarity = 1;
      cfg.hsync_pulse_width = 4;
      cfg.hsync_back_porch = 8;
      cfg.hsync_front_porch = 8;

      cfg.vsync_polarity = 1;
      cfg.vsync_pulse_width = 4;
      cfg.vsync_back_porch = 8;
      cfg.vsync_front_porch = 8;

      cfg.pclk_idle_high = 1;

      _bus_instance.config(cfg);
    }
    _panel_instance.setBus(&_bus_instance);



    {
      auto cfg = _touch_instance.config();
      cfg.x_min = 0;
      cfg.x_max = 800;
      cfg.y_min = 0;
      cfg.y_max = 480;
      cfg.pin_int = -1;
      cfg.bus_shared = false;
      cfg.offset_rotation = 0;
      cfg.i2c_port = I2C_NUM_0;
      cfg.pin_sda = GPIO_NUM_15;
      cfg.pin_scl = GPIO_NUM_16;
      cfg.pin_rst = -1;
      cfg.freq = 400000;
      cfg.i2c_addr = 0x5D;  // 0x5D , 0x14
      _touch_instance.config(cfg);
      _panel_instance.setTouch(&_touch_instance);
    }

    setPanel(&_panel_instance);
  }
};

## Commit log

2025-11-27 ディレクトリ体系化とリリース機能追加
    [gymkhana_20251124.csv]
2025-11-27 uploader-ini追加
2025-12-21 Update and rename sensor_firmware.ino to sensor_firmware_stop.ino
2026-06-15 Create Led-Panel
2026-06-15 構成変更に伴いフォルダ名修正
2026-06-15 ファイル名修正
    [gymkhana_20251124.csv]
2026-08-09 PlatformIOプロジェクト一式を追加(main.cpp以外のファイル含む)
    [partitions.csv]
2026-09-10 Refactor sensor_stop.ino to remove Ethernet support
    Removed unused Ethernet (W5500) code and updated comments. Adjusted broadcast addresses for ESP-NOW communication.
